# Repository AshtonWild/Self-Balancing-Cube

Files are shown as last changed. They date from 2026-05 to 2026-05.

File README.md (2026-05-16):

# Self-Balancing-Cube

**UPDATE (2026-05-16)**

Code is in "esp32_cube" folder. 

Pair via BlueTooth or USB Serial, there is a help menu:

=== Commands ===

h or ?   - Show help

a        - Toggle live angles

d        - Toggle debug (Serial Monitor only)

p+/p-    - Adjust K1

i+/i-    - Adjust K2

s+/s-    - Adjust K3

c+       - Start calibration

c-       - Save current position

You can print redesigned cube https://www.thingiverse.com/thing:6695891

Folow this video https://youtu.be/ZU0oTBRDgOE

---

I created a PCB with KiCad, as it was cleaner than using a prototype board and provided GERBER files for PCB Manufacturing in "Gerber".  I used JLCPCB to have the PCB built.

All parts are available via Digikey or AliExpress.  

CPU: ESP32 DEVKIT v1 Type-C

Battery: 3S1P LiPo 500 mAH (11.1V)

Motor: Nidec 24H brushless motors (8 Pin Required)

Other: Regulator (L7805), Transistor 2N2222, 5V Active Buzzer, Capacitor 100uF / 0.1uF, Register 6.8k / 33k / 10k

All red connections not nescesary for this project! But if you are designing a PCB I recommend making these connections. Maybe I use encoders in the future, you will be able to use the new firmware without any changes.
 
How to build:

https://youtu.be/AJQZFHJzwt4

If something doesn't work, try the motors test sketch. It tests all motors, rotation directions and speeds. This helps you understand the problem is in software or in hardware.

ESP32 version also has an updated balancing point setting procedure. Important! In this video you can learn how to set the balancing points:

https://youtu.be/Nkm9PoihZOI

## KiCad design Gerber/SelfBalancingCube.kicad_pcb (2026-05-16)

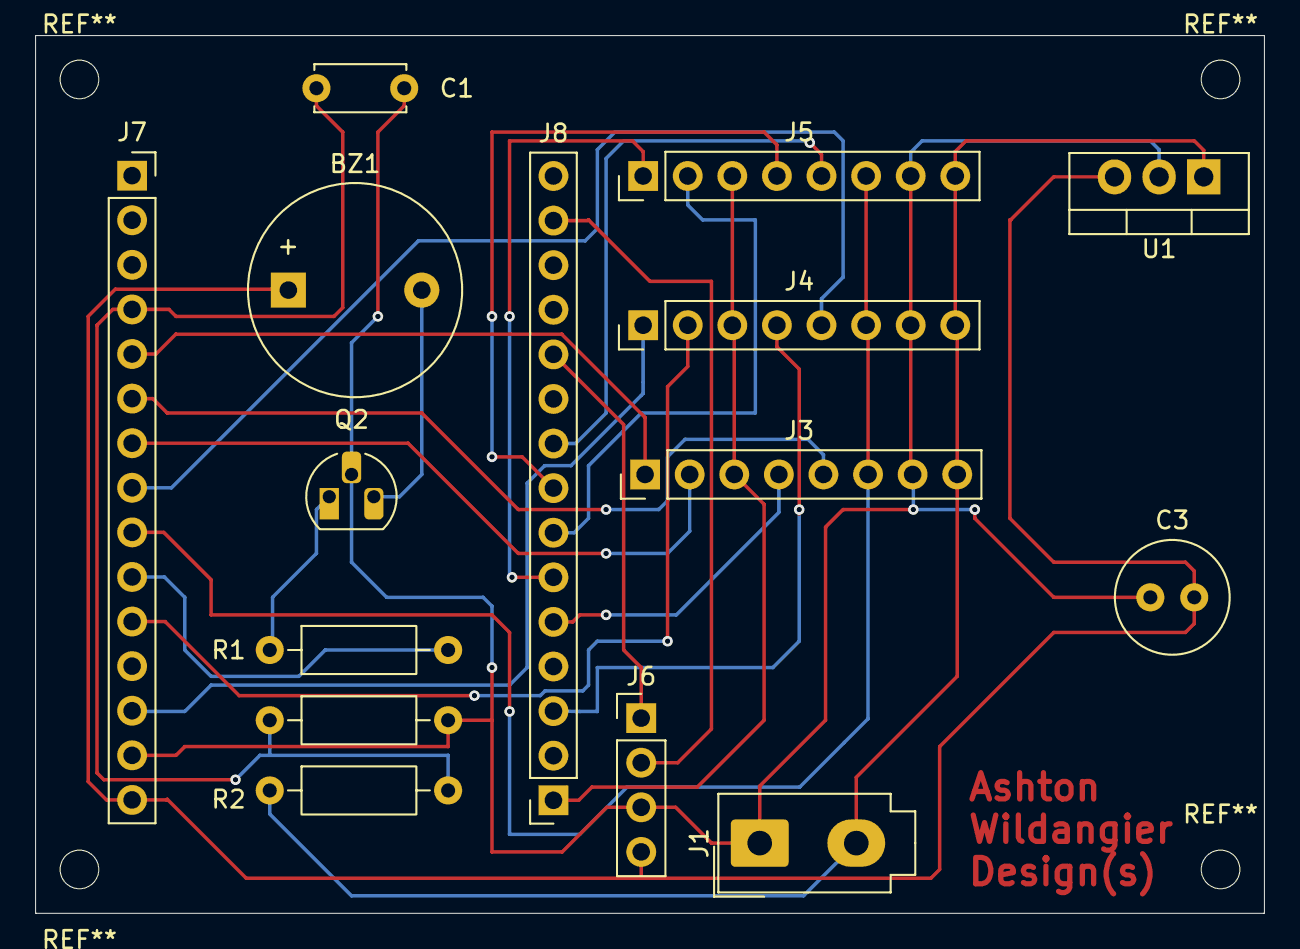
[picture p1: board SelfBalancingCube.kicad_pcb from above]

Board: 2 copper layers, 70.0 x 50.0 mm, 15 parts (0 on the bottom side), 23 nets.

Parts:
BZ1: Buzzer; Buzzer_12x9.5RM7.6
C1: C_Small_US; C_Disc_D5.0mm_W2.5mm_P5.00mm
C3: 100uF; C_Radial_D6.3mm_H7.0mm_P2.50mm
J1: Conn_01x02; Molex_Mini-Fit_Jr_5566-02A_2x01_P4.20mm_Vertical
J3, J4, J5: Nidec 24H; PinHeader_1x08_P2.54mm_Vertical
J6: Conn_01x04_Pin; PinHeader_1x04_P2.54mm_Vertical
J7, J8: Conn_01x15_Socket; PinSocket_1x15_P2.54mm_Vertical
Q2: PN2222A; TO-92_HandSolder
R1: 6.8K; R_Axial_DIN0207_L6.3mm_D2.5mm_P10.16mm_Horizontal
R2: 33K; R_Axial_DIN0207_L6.3mm_D2.5mm_P10.16mm_Horizontal
R3: 1OK; R_Axial_DIN0207_L6.3mm_D2.5mm_P10.16mm_Horizontal
U1: L7805; TO-220-3_Vertical

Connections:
unnamed: BZ1.1 (+), C3.2, J6.4, J7.15, U1.3 (OUT)
unnamed: BZ1.2 (-), Q2.3 (C)
unnamed: C1.2, C3.1, J1.1, J3.7, J4.7, J5.7, J6.3, J7.14, Q2.2 (B), R3.2, U1.2 (GND)
unnamed: J1.2, J3.8, J4.8, J5.8, R2.1, U1.1 (IN)
unnamed: J3.1, J7.5
unnamed: J3.2, J7.7
unnamed: J3.3, J4.3, J5.3, J8.1
unnamed: J3.4, J8.5
unnamed: J3.5, J7.6
unnamed: J3.6, J4.6, J5.6, J7.9
unnamed: J4.1, J7.13
unnamed: J4.2, J7.11
unnamed: J4.4, J8.3
unnamed: J4.5, J7.8
unnamed: J5.1, J8.6
unnamed: J5.2, J8.7
unnamed: J5.4, J8.8
unnamed: J5.5, J8.9
unnamed: J6.1, J8.11
unnamed: J6.2, J8.14
unnamed: C1.1, J7.4, R2.2, R3.1
unnamed: J7.10, R1.2
unnamed: Q2.1 (E), R1.1

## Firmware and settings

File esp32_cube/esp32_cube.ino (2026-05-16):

// ================================================
// ESP32 Self-Balancing Cube - Full Complete Code
// Latest upright reading: X ≈ -149, Y ≈ 91
// ================================================

#include <Wire.h>
#include <EEPROM.h>
#include "BluetoothSerial.h"

BluetoothSerial SerialBT;

// ================== PIN DEFINITIONS ==================
#define BUZZER      27
#define VBAT        34
#define BRAKE       26

#define DIR1        4
#define PWM1        32
#define DIR2        15
#define PWM2        25
#define DIR3        5
#define PWM3        18

#define TIMER_BIT   8
#define BASE_FREQ   20000

#define MPU6050     0x68
#define ACCEL_CONFIG 0x1C
#define GYRO_CONFIG  0x1B
#define PWR_MGMT_1  0x6B

#define accSens     0
#define gyroSens    1

#define EEPROM_SIZE 64

// ================== VARIABLES ==================
float K1 = 160.0f;
float K2 = 10.50f;
float K3 = 0.03f;

int   loop_time = 10;

float Gyro_amount = 0.1f;
float alpha = 0.74f;

bool vertical = false;
bool calibrating = false;
bool calibrated = false;
int  balancing_point = 0;

struct OffsetsObj {
  int   ID1, ID2, ID3, ID4;
  float X1, Y1, X2, Y2, X3, Y3, X4, Y4;
};

OffsetsObj offsets = {0};

int16_t AcX, AcY, AcZ, GyX, GyY, GyZ;
int16_t GyX_offset = 0, GyY_offset = 0, GyZ_offset = 0;

float robot_angleX = 0.0f, robot_angleY = 0.0f;
float angleX = 0.0f, angleY = 0.0f;

float gyroY = 0.0f, gyroZ = 0.0f;
float gyroYfilt = 0.0f, gyroZfilt = 0.0f;

int32_t motor_speed_X = 0;
int32_t motor_speed_Y = 0;

unsigned long currentT = 0, previousT_1 = 0, previousT_2 = 0;
unsigned long lastTipTime = 0;

bool showLiveAngle = false;
bool debugMode = false;

// === YOUR MEASURED UPRIGHT OFFSET (updated) ===
const float UPRIGHT_X_OFFSET = -149.0f;
const float UPRIGHT_Y_OFFSET = 91.4f;

// ================== SETUP ==================
void setup() {
  Serial.begin(115200);
  SerialBT.begin("ESP32-AshtonCube");

  EEPROM.begin(EEPROM_SIZE);

  pinMode(BUZZER, OUTPUT);
  pinMode(BRAKE, OUTPUT);
  digitalWrite(BRAKE, LOW);

  pinMode(DIR1, OUTPUT); 
  pinMode(DIR2, OUTPUT); 
  pinMode(DIR3, OUTPUT);

  ledcAttach(PWM1, BASE_FREQ, TIMER_BIT);
  ledcAttach(PWM2, BASE_FREQ, TIMER_BIT);
  ledcAttach(PWM3, BASE_FREQ, TIMER_BIT);

  Motor1_control(0);
  Motor2_control(0);
  Motor3_control(0);

  EEPROM.get(0, offsets);
  calibrated = (offsets.ID1 == 99 && offsets.ID2 == 99 && offsets.ID3 == 99 && offsets.ID4 == 99);

  robot_angleX = robot_angleY = angleX = angleY = 0.0f;
  motor_speed_X = motor_speed_Y = 0;
  gyroYfilt = gyroZfilt = 0.0f;

  delay(2000);

  digitalWrite(BUZZER, HIGH); delay(70); digitalWrite(BUZZER, LOW);

  angle_setup();

  Serial.println("=== ESP32 Cube Ready ===");
  SerialBT.println("Cube Ready! Send 'h' for help");
}

// ================== LOOP ==================
void loop() {
  currentT = millis();

  if (currentT - previousT_1 >= loop_time) {
    Tuning();
    angle_calc();

    if (showLiveAngle) {
      SerialBT.printf("Live → X: %.2f   Y: %.2f\n", angleX, angleY);
    }

    if (debugMode) {
      Serial.printf("Debug | X:%.2f  Y:%.2f  | BalPt:%d  | Vert:%s\n",
                    angleX, angleY, balancing_point, vertical ? "YES" : "NO");
    }

    if (vertical && calibrated && !calibrating) {
      digitalWrite(BRAKE, HIGH);

      gyroZ = GyZ / 131.0f;
      gyroY = GyY / 131.0f;

      gyroYfilt = alpha * gyroY + (1.0f - alpha) * gyroYfilt;
      gyroZfilt = alpha * gyroZ + (1.0f - alpha) * gyroZfilt;

      float correctedX = angleX - UPRIGHT_X_OFFSET;
      float correctedY = angleY - UPRIGHT_Y_OFFSET;

      float pwm_X = K1 * correctedX + K2 * gyroZfilt + K3 * motor_speed_X;
      float pwm_Y = K1 * correctedY + K2 * gyroYfilt + K3 * motor_speed_Y;

      pwm_X = constrain(pwm_X, -255.0f, 255.0f);
      pwm_Y = constrain(pwm_Y, -255.0f, 255.0f);

      motor_speed_X += (int32_t)pwm_X;
      motor_speed_Y += (int32_t)pwm_Y;

      if (balancing_point == 1) XY_to_threeWay(-pwm_X, -pwm_Y);
      else if (balancing_point == 2) Motor1_control((int)pwm_Y);
      else if (balancing_point == 3) Motor2_control(-(int)pwm_Y);
      else if (balancing_point == 4) Motor3_control((int)pwm_X);
    } else {
      XY_to_threeWay(0, 0);
      digitalWrite(BRAKE, LOW);
      motor_speed_X = motor_speed_Y = 0;
    }

    previousT_1 = currentT;
  }

  if (currentT - previousT_2 >= 2000) {
    battVoltage((double)analogRead(VBAT) / 207.0);

    if (!calibrated && !calibrating && (currentT - lastTipTime > 10000)) {
      SerialBT.println("Tip: Send 'h' for help");
      lastTipTime = currentT;
    }
    previousT_2 = currentT;
  }
}

// ================== TUNING ==================
int Tuning() {
  if (!SerialBT.available()) return 0;

  char param = SerialBT.read();
  char cmd = ' ';

  if (param != 'h' && param != '?' && param != 'a' && param != 'd') {
    if (!SerialBT.available()) return 0;
    cmd = SerialBT.read();
  }

  switch (param) {
    case 'h': 
    case '?':
      showHelp();
      break;

    case 'a':
      showLiveAngle = !showLiveAngle;
      SerialBT.print("Live angles: ");
      SerialBT.println(showLiveAngle ? "ON" : "OFF");
      break;

    case 'd':
      debugMode = !debugMode;
      SerialBT.print("Debug mode: ");
      SerialBT.println(debugMode ? "ON" : "OFF");
      Serial.print("Debug mode: ");
      Serial.println(debugMode ? "ON" : "OFF");
      break;

    case 'p':
      if (cmd == '+') K1 += 1.0f;
      if (cmd == '-') K1 -= 1.0f;
      printValues();
      break;

    case 'i':
      if (cmd == '+') K2 += 0.05f;
      if (cmd == '-') K2 -= 0.05f;
      printValues();
      break;

    case 's':
      if (cmd == '+') K3 += 0.005f;
      if (cmd == '-') K3 -= 0.005f;
      printValues();
      break;

    case 'c':
      if (cmd == '+' && !calibrating) {
        calibrating = true;
        SerialBT.println("\n=== CALIBRATION ===");
        SerialBT.println("Hold cube upright on vertex steadily");
        SerialBT.println("Send 'c-' when readings are stable");
      }
      if (cmd == '-' && calibrating) {
        float avgX = 0.0f, avgY = 0.0f;
        for (int i = 0; i < 25; i++) {
          angle_calc();
          avgX += angleX;
          avgY += angleY;
          delay(12);
        }
        avgX /= 25.0f;
        avgY /= 25.0f;

        SerialBT.printf("Measured Raw → X: %.2f   Y: %.2f\n", avgX, avgY);

        // Forgiving tolerance for your hardware
        if (abs(avgX + 145) < 30 && abs(avgY - 91) < 15) {
          offsets.ID1 = 99;
          offsets.X1 = avgX;
          offsets.Y1 = avgY;
          SerialBT.println("✅ Vertex (Upright) saved successfully!");
          save();
        }
        else if (avgX > -50 && avgX < -20 && avgY > -35 && avgY < -5) {
          offsets.ID2 = 99; offsets.X2 = avgX; offsets.Y2 = avgY;
          SerialBT.println("✅ Edge 1 saved!");
          save();
        }
        else if (avgX > 15 && avgX < 50 && avgY > -35 && avgY < -5) {
          offsets.ID3 = 99; offsets.X3 = avgX; offsets.Y3 = avgY;
          SerialBT.println("✅ Edge 2 saved!");
          save();
        }
        else if (abs(avgX) < 20 && avgY > 25 && avgY < 60) {
          offsets.ID4 = 99; offsets.X4 = avgX; offsets.Y4 = avgY;
          SerialBT.println("✅ Edge 3 saved!");
          save();
        }
        else {
          SerialBT.println("❌ Out of range. Hold steadier and try again.");
          beep(); beep();
        }
      }
      break;
  }
  return 1;
}

void showHelp() {
  SerialBT.println("\n=== Commands ===");
  SerialBT.println("h or ?   - Show help");
  SerialBT.println("a        - Toggle live angles");
  SerialBT.println("d        - Toggle debug (Serial Monitor only)");
  SerialBT.println("p+/p-    - Adjust K1");
  SerialBT.println("i+/i-    - Adjust K2");
  SerialBT.println("s+/s-    - Adjust K3");
  SerialBT.println("c+       - Start calibration");
  SerialBT.println("c-       - Save current position");
}

void printValues() {
  SerialBT.printf("K1=%.1f  K2=%.2f  K3=%.4f\n", K1, K2, K3);
}

// ================== HELPER FUNCTIONS ==================
void writeTo(byte device, byte address, byte value) {
  Wire.beginTransmission(device);
  Wire.write(address);
  Wire.write(value);
  Wire.endTransmission(true);
}

void beep() {
  digitalWrite(BUZZER, HIGH); delay(70); digitalWrite(BUZZER, LOW); delay(80);
}

void save() {
  EEPROM.put(0, offsets);
  EEPROM.commit();
  EEPROM.get(0, offsets);
  calibrated = true;
  calibrating = false;
  SerialBT.println("Calibration saved.");
  beep();
}

void angle_setup() {
  Wire.begin();
  Wire.setClock(400000);
  delay(100);
  writeTo(MPU6050, PWR_MGMT_1, 0);
  writeTo(MPU6050, ACCEL_CONFIG, accSens << 3);
  writeTo(MPU6050, GYRO_CONFIG, gyroSens << 3);
  delay(100);

  long sumX = 0, sumY = 0, sumZ = 0;
  for (int i = 0; i < 1024; i++) {
    angle_calc();
    sumX += GyX; sumY += GyY; sumZ += GyZ;
    delay(3);
  }
  GyX_offset = sumX >> 10;
  GyY_offset = sumY >> 10;
  GyZ_offset = sumZ >> 10;
  beep(); beep(); beep();
}

void angle_calc() {
  Wire.beginTransmission(MPU6050); Wire.write(0x43); Wire.endTransmission(false);
  Wire.requestFrom(MPU6050, 6, true);
  GyX = (Wire.read() << 8) | Wire.read();
  GyY = (Wire.read() << 8) | Wire.read();
  GyZ = (Wire.read() << 8) | Wire.read();

  Wire.beginTransmission(MPU6050); Wire.write(0x3B); Wire.endTransmission(false);
  Wire.requestFrom(MPU6050, 6, true);
  AcX = (Wire.read() << 8) | Wire.read();
  AcY = (Wire.read() << 8) | Wire.read();
  AcZ = (Wire.read() << 8) | Wire.read();

  GyX -= GyX_offset;
  GyY -= GyY_offset;
  GyZ -= GyZ_offset;

  robot_angleX += (float)GyZ * loop_time / 1000.0f / 65.536f;
  float Acc_angleX = atan2(AcY, -AcX) * 57.2958f;
  robot_angleX = robot_angleX * Gyro_amount + Acc_angleX * (1.0f - Gyro_amount);

  robot_angleY += (float)GyY * loop_time / 1000.0f / 65.536f;
  float Acc_angleY = -atan2(AcZ, -AcX) * 57.2958f;
  robot_angleY = robot_angleY * Gyro_amount + Acc_angleY * (1.0f - Gyro_amount);

  angleX = robot_angleX;
  angleY = robot_angleY;
}

void XY_to_threeWay(float pwm_X, float pwm_Y) {
  int16_t m1 = round(0.5f * pwm_X - 0.75f * pwm_Y);
  int16_t m2 = round(0.5f * pwm_X + 0.75f * pwm_Y);
  int16_t m3 = round(-pwm_X);
  Motor1_control(constrain(m1, -255, 255));
  Motor2_control(constrain(m2, -255, 255));
  Motor3_control(constrain(m3, -255, 255));
}

void battVoltage(double voltage) {
  digitalWrite(BUZZER, (voltage > 8.0 && voltage <= 9.5) ? HIGH : LOW);
}

void Motor1_control(int sp) {
  digitalWrite(DIR1, (sp >= 0) ? HIGH : LOW);
  ledcWrite(PWM1, constrain(abs(sp), 0, 255));
}

void Motor2_control(int sp) {
  digitalWrite(DIR2, (sp >= 0) ? HIGH : LOW);
  ledcWrite(PWM2, constrain(abs(sp), 0, 255));
}

void Motor3_control(int sp) {
  digitalWrite(DIR3, (sp >= 0) ? HIGH : LOW);
  ledcWrite(PWM3, constrain(abs(sp), 0, 255));
}

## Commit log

2026-11-12 Code Re-Write to Better Calibrate Cube
2026-11-12 Revise README with updated information and commands
    Updated the README with new instructions and calibration steps.
